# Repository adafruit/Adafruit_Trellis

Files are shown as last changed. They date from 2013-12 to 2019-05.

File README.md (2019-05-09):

# CAD & PCB data for the Adafruit Trellis keypad & control PCB

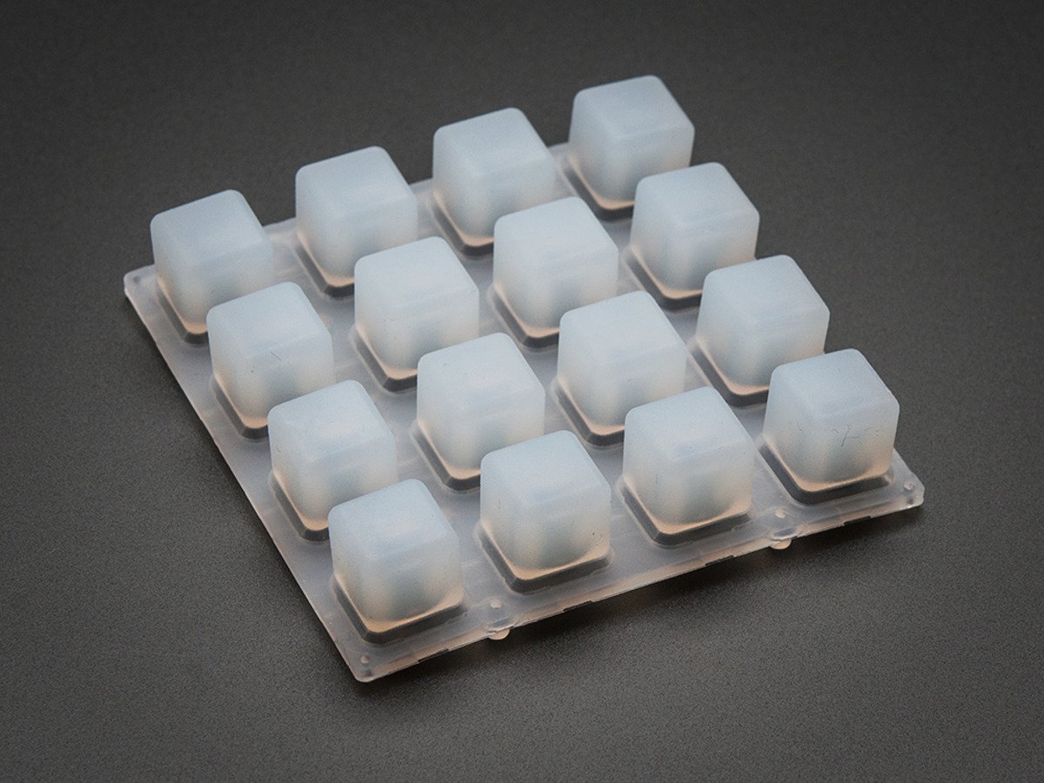
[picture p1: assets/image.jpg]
<a href="http://www.adafruit.com/products/1611"><br/>Click here to purchase one from the Adafruit shop</a>

* [Silicone Elastomer 4x4 Button Keypad - for 3mm LEDs](https://www.adafruit.com/product/1611)
* [Small 1.2" 8x8 Ultra Bright White LED Matrix + Backpack](https://www.adafruit.com/product/1614)

So squishy! These silicone elastomer keypads are just waiting for your fingers to press them. Go ahead, squish all you like! (They're durable and easy to clean, just wipe with mild soap and water) These are just like the light up rubber buttons you find on stuff like appliances and tools, but these are open source and easy to integrate into your next project.

Each button is 10mm x 10mm square and 10mm tall. There is 5mm of grid spacing between the buttons. You can 'tile' the button pads edge-to-edge and they'll grid up correctly. You can also cut the pads down if you like, the silicone is very soft. The way they're molded, they give about 3mm of travel when pressed for a very satisfying feel. They are completely quiet, however.

On the bottom of each button is a conductive pad ring which can close a properly design contact underneath. [We have an EagleCad library which has objects for the buttons and optional LEDs so you can use them in your next PCB design.](https://github.com/adafruit/Adafruit_Trellis).

Each button is 10mm tall and can fit a 3mm LED inside quite easily. 5mm LEDs are too big, so stick with 3mm here. The LED is optional, having it or not does not affect the 'action'. but it's nice to backlight buttons. Diffused LEDs are best, [so check out our offerings: the blue, white and red look best, if you're sourcing your own LEDs go for something with 300mcd or greater brightness. Diffused looks better than not.](https://www.adafruit.com/search?q=led+diffused+3mm).

[Chances are you don't want to make your own PCB, so pick up an Adafruit Trellis, our tile-able driver which can control 16 LEDs + these 16 buttons over I2C](https://www.adafruit.com/products/1616).

## License

Adafruit invests time and resources providing this open source design, 
please support Adafruit and open-source hardware by purchasing 
products from Adafruit!

Designed by Adafruit Industries.  
GNU Public License v2
All text above must be included in any redistribution

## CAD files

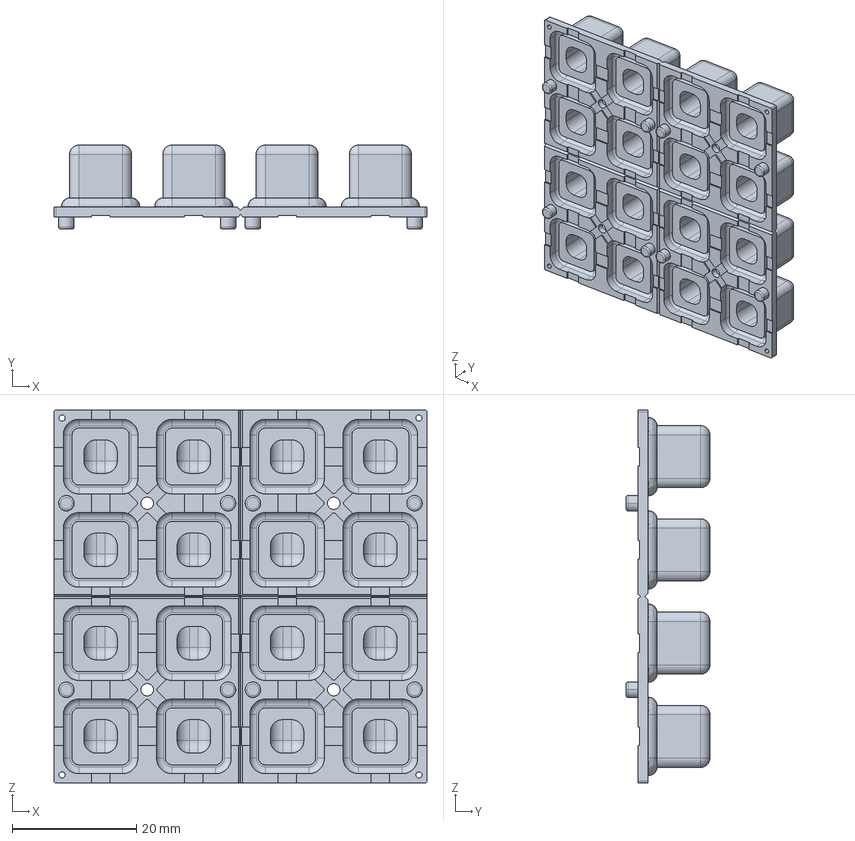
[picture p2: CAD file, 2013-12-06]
Adafruit Trellis 3mm.stp
60.0 x 13.5 x 60.0 mm

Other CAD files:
Adafruit Trellis 3mm.stl

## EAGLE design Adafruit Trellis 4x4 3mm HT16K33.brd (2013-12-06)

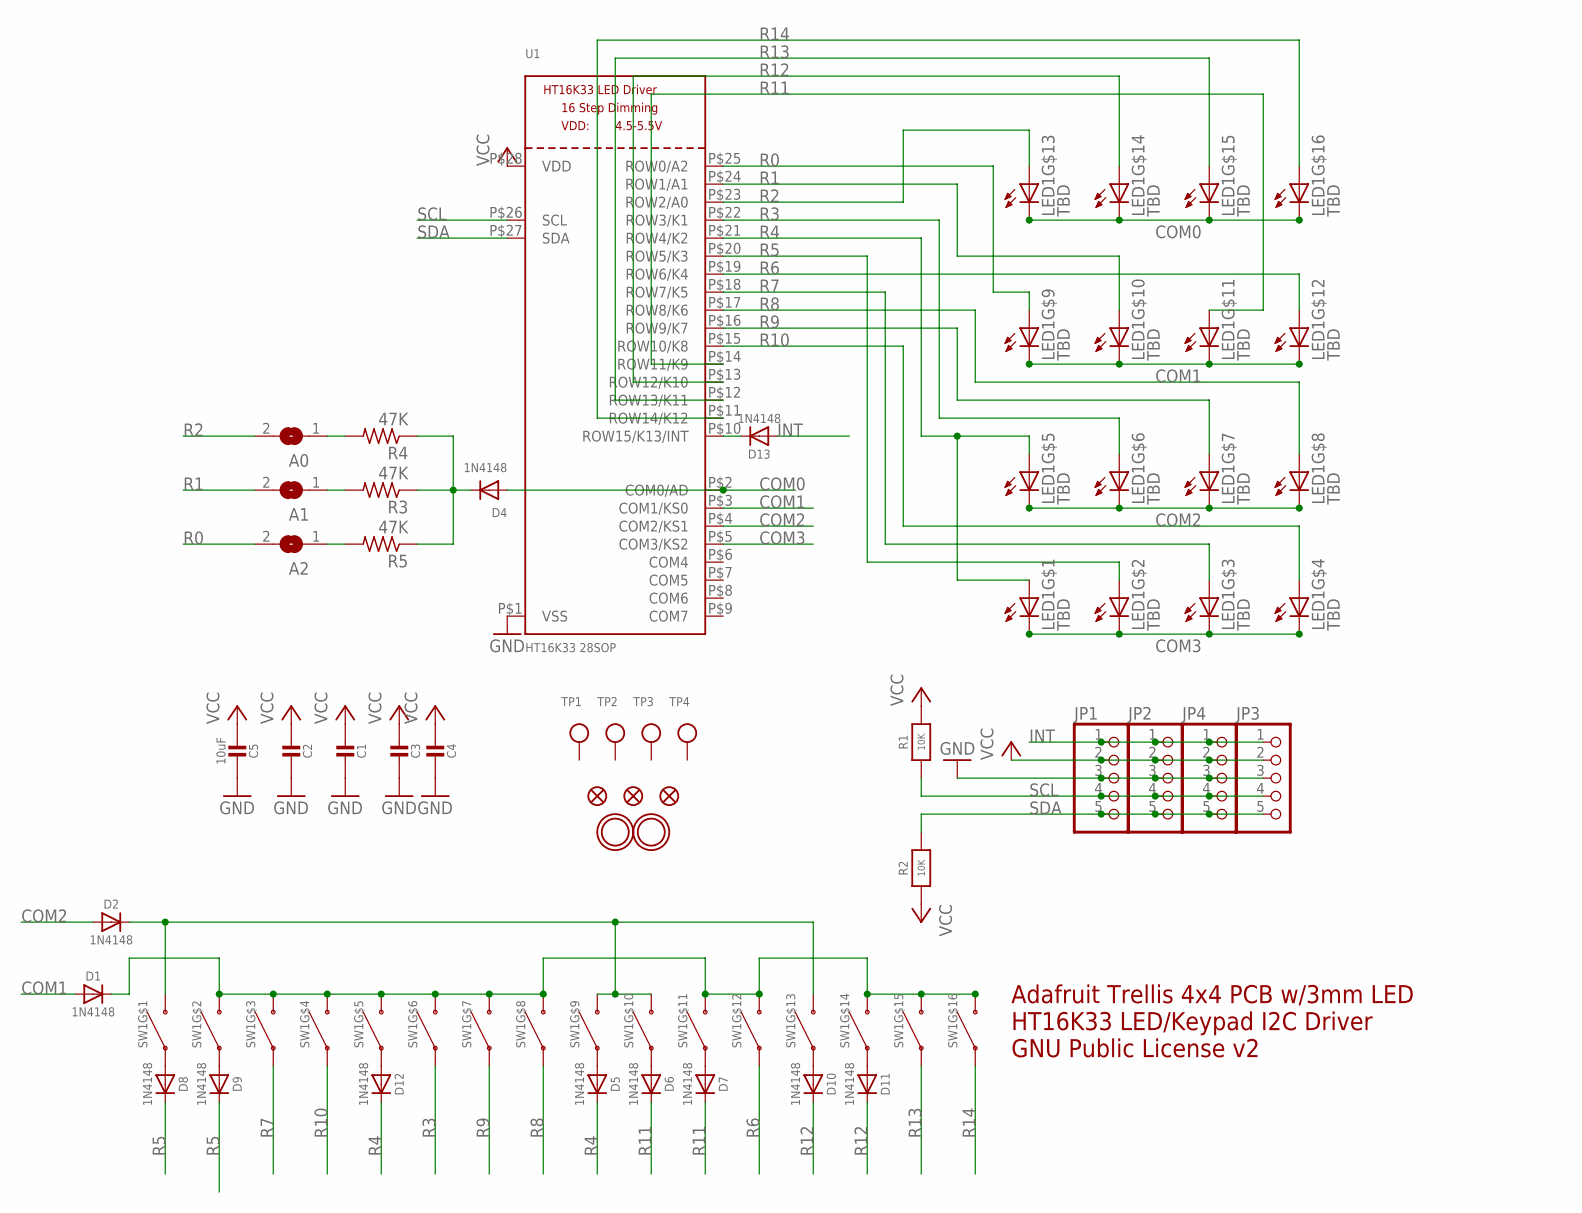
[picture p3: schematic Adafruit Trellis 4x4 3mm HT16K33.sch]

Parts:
A0, A1, A2: SOLDERJUMPERREFLOW_NOPASTE; SOLDERJUMPER_REFLOW_NOPASTE
C1, C2, C3, C4: CAP_CERAMIC_0805; _0805
C5: 10uF; _0805
D1, D2, D5, D6, D7, D8, D9, D10, D11, D12, D13: 1N4148; SOD-323
D4: 1N4148; SOD-323F
FID1, FID2, FID3: FIDUCIAL""; FIDUCIAL_1MM
JP1, JP2, JP3, JP4: HEADER-1X5EDGESMT; 1X5_SMT
LED1: TBD; LED3MM-4X4GRID
R1, R2: 10K; _0805
R3, R4, R5: 47K; R0805
SW1: SWITCH-SILICON-4X4GRID-10MM-5.4MM; ELAST_PAD_SQUARE_10MM_5.4MM_4X4GRID
TP1, TP2, TP3, TP4: TESTPOINT; TESTPOINT_SMT
U1: HT16K33 28SOP; SOP28_300MIL
U$1, U$2: MOUNTINGHOLE2.5; MOUNTINGHOLE_2.5_PLATED

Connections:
COM0: D4.A, LED1.K13 (C), LED1.K14 (C), LED1.K15 (C), LED1.K16 (C), U1.P$2 (COM0/AD)
COM1: D1.A, LED1.K9 (C), LED1.K10 (C), LED1.K11 (C), LED1.K12 (C), U1.P$3 (COM1/KS0)
COM2: D2.A, LED1.K5 (C), LED1.K6 (C), LED1.K7 (C), LED1.K8 (C), U1.P$4 (COM2/KS1)
COM3: LED1.K1 (C), LED1.K2 (C), LED1.K3 (C), LED1.K4 (C), U1.P$5 (COM3/KS2)
GND: C1.1, C2.1, C3.1, C4.1, C5.1, JP1.3, JP2.3, JP3.3, JP4.3, U1.P$1 (VSS)
INT: D13.A, JP1.1, JP2.1, JP3.1, JP4.1
unnamed: D2.C, SW1.B1, SW1.B9, SW1.B10, SW1.B13
unnamed: D13.C, U1.P$10 (ROW15/K13/INT)
unnamed: D5.A, SW1.A9
unnamed: D6.A, SW1.A10
unnamed: D1.C, SW1.B2, SW1.B3, SW1.B4, SW1.B5, SW1.B6, SW1.B7, SW1.B8, SW1.B11, SW1.B12, SW1.B14, SW1.B15, SW1.B16
unnamed: D7.A, SW1.A11
unnamed: D8.A, SW1.A1
unnamed: D9.A, SW1.A2
unnamed: A2.1, R5.2
unnamed: D10.A, SW1.A13
unnamed: D11.A, SW1.A14
unnamed: D12.A, SW1.A5
unnamed: D4.C, R3.1, R4.1, R5.1
unnamed: A1.1, R3.2
unnamed: A0.1, R4.2
R0: A2.2, LED1.A9 (A), U1.P$25 (ROW0/A2)
R1: A1.2, LED1.A10 (A), U1.P$24 (ROW1/A1)
R2: A0.2, LED1.A13 (A), U1.P$23 (ROW2/A0)
R3: LED1.A6 (A), SW1.A6, U1.P$22 (ROW3/K1)
R4: D5.C, D12.C, LED1.A1 (A), LED1.A5 (A), U1.P$21 (ROW4/K2)
R5: D8.C, D9.C, LED1.A2 (A), U1.P$20 (ROW5/K3)
R6: LED1.A12 (A), SW1.A12, U1.P$19 (ROW6/K4)
R7: LED1.A3 (A), SW1.A3, U1.P$18 (ROW7/K5)
R8: LED1.A8 (A), SW1.A8, U1.P$17 (ROW8/K6)
R9: LED1.A7 (A), SW1.A7, U1.P$16 (ROW9/K7)
R10: LED1.A4 (A), SW1.A4, U1.P$15 (ROW10/K8)
R11: D6.C, D7.C, LED1.A11 (A), U1.P$14 (ROW11/K9)
R12: D10.C, D11.C, LED1.A14 (A), U1.P$13 (ROW12/K10)
R13: LED1.A15 (A), SW1.A15, U1.P$12 (ROW13/K11)
R14: LED1.A16 (A), SW1.A16, U1.P$11 (ROW14/K12)
SCL: JP1.4, JP2.4, JP3.4, JP4.4, R1.1, U1.P$26 (SCL)
SDA: JP1.5, JP2.5, JP3.5, JP4.5, R2.2, U1.P$27 (SDA)
VCC: C1.2, C2.2, C3.2, C4.2, C5.2, JP1.2, JP2.2, JP3.2, JP4.2, R1.2, R2.1, U1.P$28 (VDD)

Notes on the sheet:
Adafruit Trellis 4x4 PCB w/3mm LED HT16K33 LED/Keypad I2C Driver GNU Public License v2

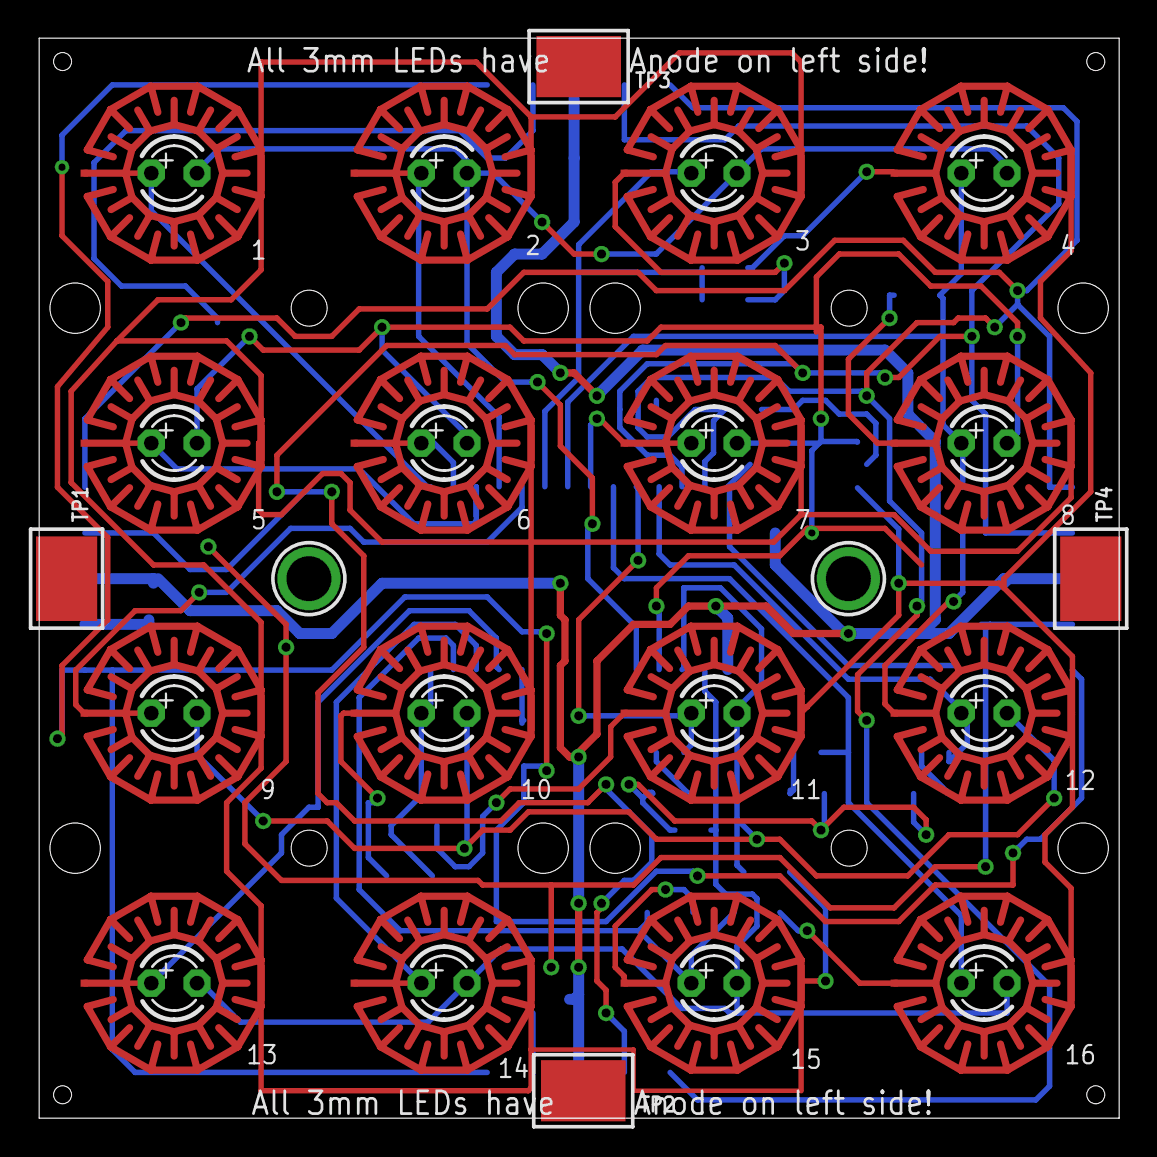
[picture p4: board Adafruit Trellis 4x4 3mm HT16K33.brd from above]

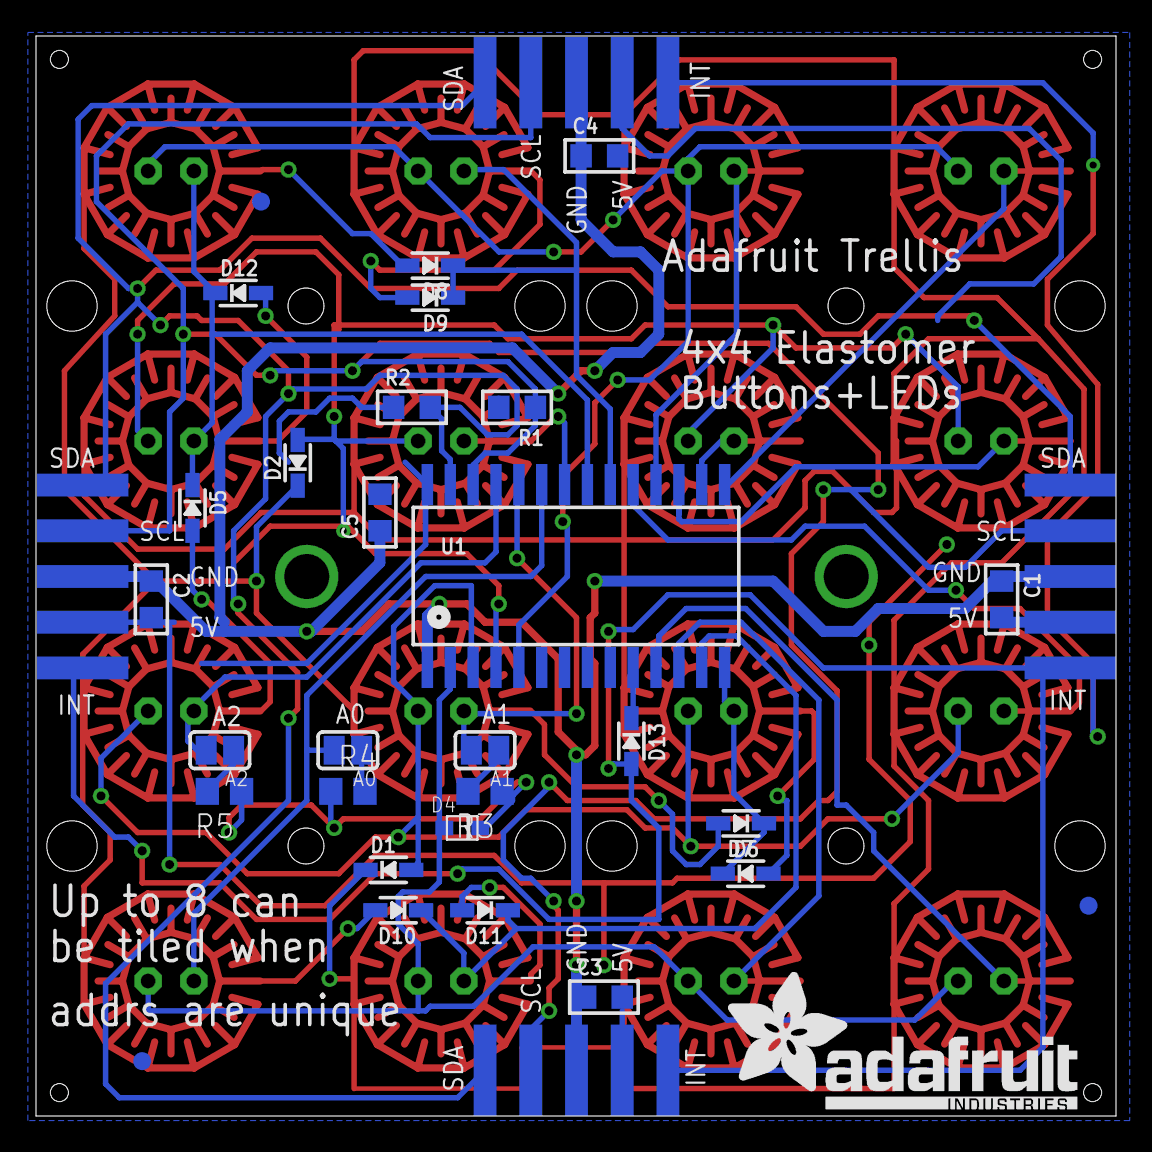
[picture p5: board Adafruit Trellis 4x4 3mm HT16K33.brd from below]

Board: 2 copper layers, 60.0 x 60.0 mm, 42 parts (34 on the bottom side), 39 nets.

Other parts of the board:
U$3: ADAFRUIT_TEXT_20MM

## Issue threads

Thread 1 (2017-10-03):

16x8 HELLA OONTZ UNTZtrument

IntegersOfK, 2017-10-03:
Hi I bought all the stuff to build the large 16x8 UNTZtrument at https://www.adafruit.com/product/1999 except I didn't buy the actual kit itself because I had hoped to print/cut the plastic case on my own from this repo. But I don't see the big one here (there is only 8x8 and smaller available to download).

Obviously adafruit has a file they're using to laser cut these acrylic cases for the kit. I don't have a ton of experience modelling, so I'd really appreciate it if you could upload that file to print/cut.

Thank you,
AJ West

heuermh, 2019-09-06:
Hello @IntegersOfK, the SVG files for the 16x8 are available here

https://learn.adafruit.com/untztrument-trellis-midi-instrument/downloads

However, when I copy the button cutouts from these SVGs into a Ponoko SVG template, for laser cutting using their service, the button sizes do not appear to be correct. The Silicone Elastomer 4x4 Button Keypads measure 6 cm on a side, but the shapes after pasting via Inkscape are much smaller.

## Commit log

2013-12-06 STEP original & STL convert
    [Adafruit Trellis 3mm.stl, Adafruit Trellis 3mm.stp]
2013-12-06 Eagle Files
    [Adafruit Trellis 4x4 3mm HT16K33.brd, Adafruit Trellis 4x4 3mm HT16K33.sch]

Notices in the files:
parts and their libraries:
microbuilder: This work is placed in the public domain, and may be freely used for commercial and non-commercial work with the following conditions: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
